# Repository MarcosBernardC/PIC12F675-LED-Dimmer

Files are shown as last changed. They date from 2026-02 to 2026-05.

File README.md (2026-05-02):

# PIC12F675 LED Dimmer





> **Nota:** Este proyecto ha sido migrado al **ARCHIVE**. Representa una base estable de control de potencia y gestión de recursos limitados en sistemas embebidos.

## 🚧 Avance Actual: Diseño de PCB y Modelado 3D
Actualmente, he finalizado el esquema lógico y la disposición de componentes principales. El siguiente paso es la integración de un módulo Buck Step-Down personalizado (LM2596) modelado en FreeCAD para mejorar la eficiencia térmica.

### Captura del Layout Preliminar
Aquí puedes ver la disposición actual de los transistores 2N2222A y los conectores JST para las 5 salidas LED.
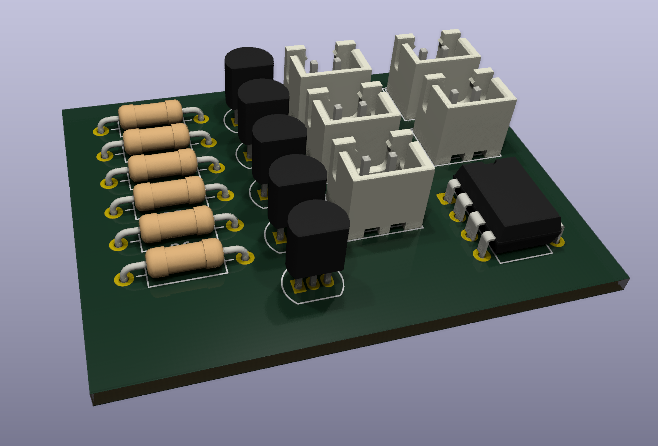
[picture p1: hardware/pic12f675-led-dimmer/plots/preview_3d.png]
Layout 3D Preliminar


---

## 📝 Descripción
Controlador de intensidad (Dimmer) de 5 canales para tiras LED de 12V, basado en el microcontrolador PIC12F675. 

* **Control:** PWM generado por software.
* **Potencia:** Transistores 2N2222A en configuración de conmutación.
* **Eficiencia:** Integración de regulador Buck LM2596 para reducir de 12V a 5V sin generar calor excesivo.

### 📂 Documentación de Hardware
Para una revisión detallada de las conexiones, consulta el <a href="https://raw.githubusercontent.com/MarcosBernardC/PIC12F675-LED-Dimmer/main/hardware/pic12f675-led-dimmer/pic12f675-led-dimmer.pdf" 
   target="_blank" 
   rel="noopener noreferrer">
   📄 <strong>Diagrama Técnico (PDF)</strong>
</a>

---

## 🧠 Firmware
El núcleo del sistema está escrito en **C** y optimizado para el PIC12F675 utilizando el compilador **XC8**.

* **Arquitectura:** Basada en interrupciones para una gestión eficiente del PWM.
* **Módulos clave:**  
    * Gestión de 5 canales de salida mediante conmutación rápida.
    * Configuración de registros internos (Oscilador, GPIO, Timers).

* **Código Fuente:** <a href="https://raw.githubusercontent.com/MarcosBernardC/PIC12F675-LED-Dimmer/main/src/main.c" target="_blank">📄 main.c (Vista Raw)</a>

---

## 🛠️ Herramientas utilizadas
* **Firmware:** C (XC8 Compiler), MPLAB X.
* **Diseño PCB:** KiCad 8.0.
* **Modelado 3D:** FreeCAD (integración paramétrica).
* **Automatización:** `Makefile` para compilación y gestión de assets.
* **Documentación:** LaTeX para el reporte de investigación.

---

## 📁 Estructura del Proyecto
* `/src`: Código fuente en C y artefactos de compilación (`.hex`).
* `/hardware`: Archivos de diseño de KiCad 8.0 y exportaciones PDF.
* `/docs`: Datasheets e investigación técnica detallada en LaTeX.
* `/simulation`: Archivos de simulación para validación lógica previa.
* `Makefile`: Automatización de la compilación del firmware.

---

## 🚀 Compilación y Uso
El proyecto utiliza un `Makefile` para automatizar las tareas:
* `make`: Compila el código fuente y genera el `.hex`.
* `make clean`: Limpia los archivos temporales de compilación.

---

## ✅ Resultados y Pruebas
El sistema ha sido validado físicamente con los siguientes resultados:
* **Estabilidad Térmica:** El regulador Buck LM2596 mantiene una temperatura operativa estable bajo carga completa (5 tiras LED).
* **Respuesta PWM:** Conmutación limpia sin parpadeo perceptible, optimizada mediante la gestión de registros del Timer0.
* **Integración Mecánica:** El modelo 3D de FreeCAD permitió un ensamble preciso dentro de la carcasa final.

## 📜 Licencia y Autoría
Este proyecto fue desarrollado íntegramente por **Marcos Bernard Calixto**.
* **Copyright:** © 2026 - No License Granted - All Rights Reserved.

---
© 2026 MB

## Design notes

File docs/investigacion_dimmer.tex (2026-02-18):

\documentclass[12pt,a4paper]{article}
\usepackage[utf8]{inputenc}
\usepackage[spanish]{babel}
\usepackage{graphicx}
\usepackage{listings} % Para mostrar tu código C elegante
\usepackage{xcolor}
\usepackage{hyperref}

\title{Implementación de Control de Potencia PWM en Microcontroladores de 8 bits}
\author{Bernard Calixto}
\date{Febrero 2026}

\begin{document}

\maketitle

\section{Introducción}
Este proyecto documenta el diseño e implementación de un dimmer para luminarias LED utilizando el microcontrolador PIC12F675. Se prioriza la optimización de recursos y el uso de herramientas Open Source en entornos Linux (Fedora).

\section{Definición del Problema}
El presente proyecto nace de la necesidad de proporcionar una iluminación dinámica y estética para un elemento ornamental sacro: una efigie de plata con arco ornamental y cintas de seda fucsia y blanca. 

El desafío técnico se divide en tres vertientes:
\begin{itemize}
    \item \textbf{Efecto Visual:} Lograr una transición de luz suave (fading) que realce el brillo del metal y la textura de la seda sin parpadeos perceptibles.
    \item \textbf{Eficiencia Lumínica:} Optimizar la posición de los emisores para evitar la pérdida de intensidad por atenuación, descartando la iluminación posterior en favor de un enfoque frontal o lateral que resalte el relieve de la plata.
    \item \textbf{Restricción de Hardware:} Implementar el control en un microcontrolador de dimensiones reducidas (PIC12F675) para que el circuito sea discreto y transportable durante las procesiones.
\end{itemize}

\section{Cronograma de Desarrollo}
\begin{itemize}
    \item \textbf{Fase 1:} Validación de hardware (Blink LED).
    \item \textbf{Fase 2:} Implementación de ADC para control analógico.
    \item \textbf{Fase 3:} Generación de señal PWM y pruebas de carga.
\end{itemize}

\end{document}

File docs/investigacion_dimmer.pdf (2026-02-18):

# Implementación de Control de Potencia PWM en Microcontroladores de 8 bits

### Bernard Calixto

### Febrero 2026

## 1. Introducción

Este proyecto documenta el diseño e implementación de un dimmer para luminarias LED utilizando el microcontrolador PIC12F675. Se prioriza la optimización de recursos y el uso de herramientas Open Source en entornos Linux (Fedora).

## 2. Definición del Problema

El presente proyecto nace de la necesidad de proporcionar una iluminación dinámica y estética para un elemento ornamental sacro: una efigie de plata con arco ornamental y cintas de seda fucsia y blanca.
El desafío técnico se divide en tres vertientes:

Efecto Visual: Lograr una transición de luz suave (fading) que realce el brillo del metal y la textura de la seda sin parpadeos perceptibles.

Eficiencia Lumínica: Optimizar la posición de los emisores para evitar la pérdida de intensidad por atenuación, descartando la iluminación posterior en favor de un enfoque frontal o lateral que resalte el relieve de la plata.

Restricción de Hardware: Implementar el control en un microcontrolador de dimensiones reducidas (PIC12F675) para que el circuito sea discreto y transportable durante las procesiones.

1

## 3. Cronograma de Desarrollo

Fase 1: Validación de hardware (Blink LED).

Fase 2: Implementación de ADC para control analógico.

Fase 3: Generación de señal PWM y pruebas de carga.

2

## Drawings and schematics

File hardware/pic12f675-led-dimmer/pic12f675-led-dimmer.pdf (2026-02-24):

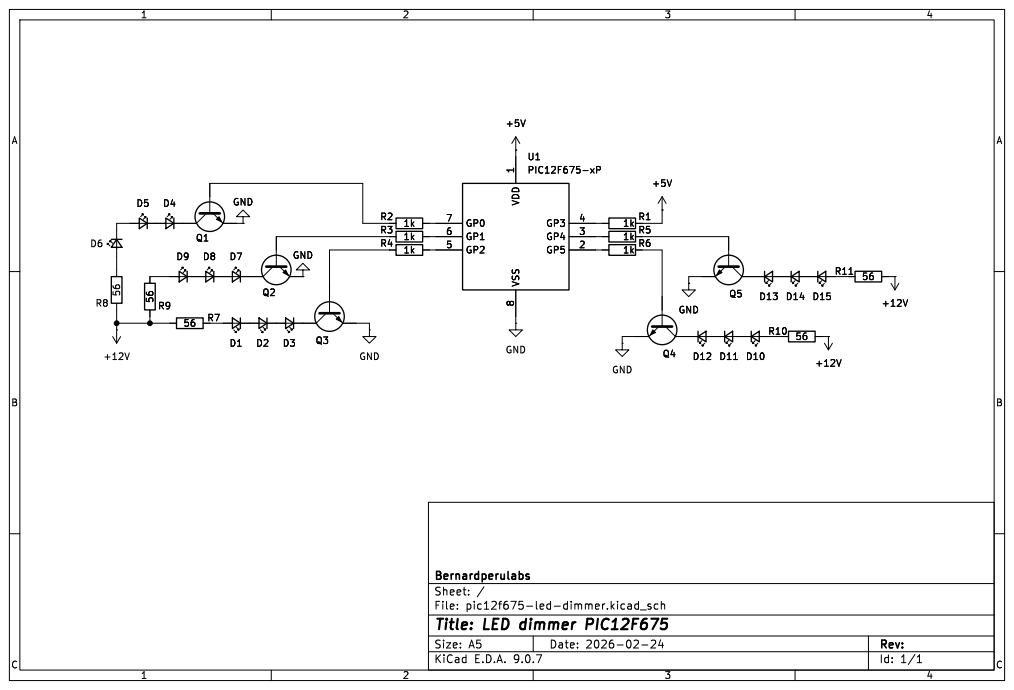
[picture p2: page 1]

Id: 1/1 Title: LED dimmer PIC12F675

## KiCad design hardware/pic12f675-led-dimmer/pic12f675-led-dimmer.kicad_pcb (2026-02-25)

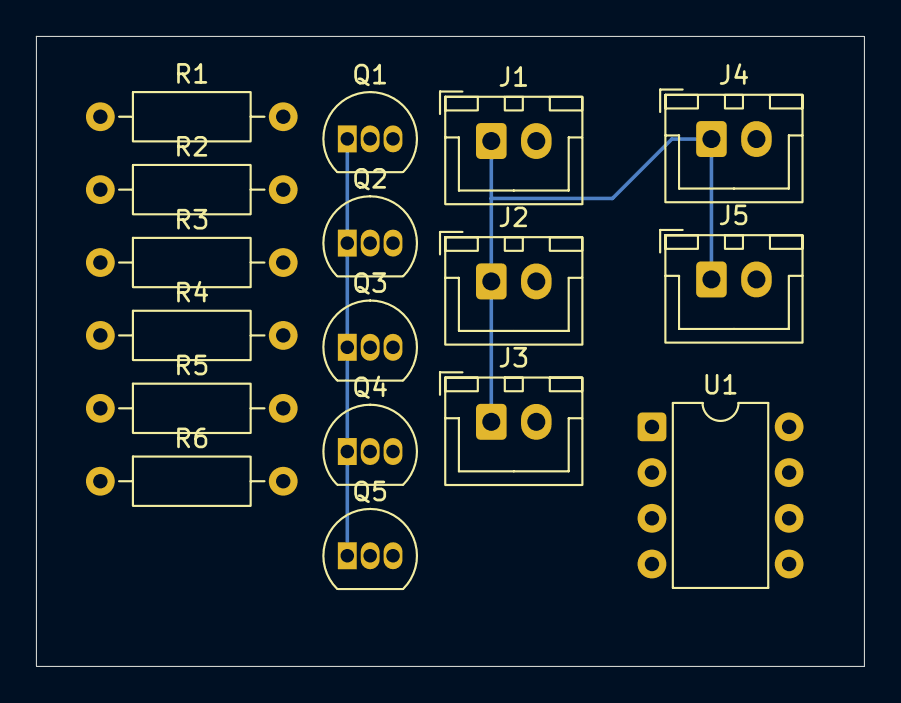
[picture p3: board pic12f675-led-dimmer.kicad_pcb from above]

Board: 2 copper layers, 46.0 x 35.0 mm, 17 parts (0 on the bottom side), 8 nets.

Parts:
J1, J2, J3, J4, J5: Conn_01x02_Pin; JST_XH_B2B-XH-A_1x02_P2.50mm_Vertical
Q1, Q2, Q3, Q4, Q5: Q_NPN; TO-92_Inline
R1, R2, R3, R4, R5, R6: 1k; R_Axial_DIN0207_L6.3mm_D2.5mm_P10.16mm_Horizontal
U1: PIC12F675-xP; DIP-8_W7.62mm

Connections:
+5V: R1.2, U1.1 (VDD)
+12V: J1.1, J2.1, J3.1, J4.1, J5.1
unnamed: R2.1, U1.7 (GP0)
unnamed: R3.1, U1.6 (GP1)
unnamed: R4.1, U1.5 (GP2)
unnamed: R1.1, U1.4 (GP3)
unnamed: R5.1, U1.3 (GP4)
unnamed: R6.1, U1.2 (GP5)

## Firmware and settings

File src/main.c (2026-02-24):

#include <xc.h>

// ---------------------------------------------------------------------------
// CONFIG — PIC12F675, fuses completos
// ---------------------------------------------------------------------------
#pragma config FOSC  = INTRCIO  // Oscilador interno, GP4/GP5 como I/O
#pragma config WDTE  = OFF      // Watchdog Timer desactivado
#pragma config PWRTE = ON       // Power-up Timer activado
#pragma config MCLRE = OFF      // GP3 como entrada digital (no reset)
#pragma config BOREN = ON       // Brown-out Reset activado
#pragma config CP    = OFF      // Sin protección de código
#pragma config CPD   = OFF      // Sin protección de datos EEPROM

#define _XTAL_FREQ 4000000UL

// ---------------------------------------------------------------------------
// Parámetros del efecto
// ---------------------------------------------------------------------------
#define PWM_STEPS   100     // Resolución PWM (0–100)
#define T0_RELOAD   156     // Timer0: tick de 200µs → PWM 50Hz @ 4MHz, prescaler 1:2
#define T1_RELOAD_H 0xF8    // Timer1: tick de 15ms @ 4MHz, prescaler 1:8
#define T1_RELOAD_L 0xED
#define ARCO_DIV    2       // Arco: 1 paso cada 2 ticks → ciclo ~6s
#define VIRGEN_DIV  4       // Virgen: 1 paso cada 4 ticks → ciclo ~12s

// ---------------------------------------------------------------------------
// Variables compartidas ISR ↔ main
// ---------------------------------------------------------------------------

// Base (GP0/GP1) — ola 3s
volatile unsigned char brillo_base   = 0;
volatile signed char   paso_base     = 1;

// Arco (GP2/GP4) — ola 6s, arranca en contrafase con base
volatile unsigned char brillo_arco   = PWM_STEPS;
volatile signed char   paso_arco     = -1;

// Virgen (GP5) — respiración lenta 12s, arranca en brillo medio
volatile unsigned char brillo_virgen = 50;
volatile signed char   paso_virgen   = 1;

// ---------------------------------------------------------------------------
// ISR
// ---------------------------------------------------------------------------
void __interrupt() isr(void) {

    // --- Timer0: PWM tick (200µs) ---
    if(INTCONbits.T0IF) {
        static unsigned char cnt = 0;

        // Base: GP0 y GP1 en contrafase
        GP0 = (cnt < brillo_base)               ? 1 : 0;
        GP1 = (cnt < (PWM_STEPS - brillo_base)) ? 1 : 0;

        // Arco: GP2 y GP4 en contrafase entre sí
        GP2 = (cnt < brillo_arco)               ? 1 : 0;
        GP4 = (cnt < (PWM_STEPS - brillo_arco)) ? 1 : 0;

        // Virgen: GP5 respiración lenta independiente
        GP5 = (cnt < brillo_virgen)             ? 1 : 0;

        if(++cnt >= PWM_STEPS) cnt = 0;

        TMR0 = T0_RELOAD;
        INTCONbits.T0IF = 0;
    }

    // --- Timer1: fade tick (15ms) ---
    if(PIR1bits.TMR1IF) {

        // -- Fade base (cada tick → ciclo ~3s) --
        if(paso_base > 0 && brillo_base >= PWM_STEPS) {
            paso_base = -1;
        } else if(paso_base < 0 && brillo_base == 0) {
            paso_base = 1;
        }
        brillo_base += paso_base;

        // -- Fade arco (cada 2 ticks → ciclo ~6s) --
        static unsigned char arco_cnt = 0;
        if(++arco_cnt >= ARCO_DIV) {
            arco_cnt = 0;
            if(paso_arco > 0 && brillo_arco >= PWM_STEPS) {
                paso_arco = -1;
            } else if(paso_arco < 0 && brillo_arco == 0) {
                paso_arco = 1;
            }
            brillo_arco += paso_arco;
        }

        // -- Fade virgen (cada 4 ticks → ciclo ~12s) --
        static unsigned char virgen_cnt = 0;
        if(++virgen_cnt >= VIRGEN_DIV) {
            virgen_cnt = 0;
            if(paso_virgen > 0 && brillo_virgen >= PWM_STEPS) {
                paso_virgen = -1;
            } else if(paso_virgen < 0 && brillo_virgen == 0) {
                paso_virgen = 1;
            }
            brillo_virgen += paso_virgen;
        }

        TMR1H = T1_RELOAD_H;
        TMR1L = T1_RELOAD_L;
        PIR1bits.TMR1IF = 0;
    }
}

// ---------------------------------------------------------------------------
// Main
// ---------------------------------------------------------------------------
void main(void) {

    ANSEL  = 0x00;
    CMCON  = 0x07;
    TRISIO = 0x00;
    GPIO   = 0x00;

    // Timer0 — preescaler 1:2, fuente interna
    OPTION_REG = 0b00000000;
    TMR0 = T0_RELOAD;
    INTCONbits.T0IE = 1;

    // Timer1 — preescaler 1:8, fuente interna
    T1CON = 0b00110001;
    TMR1H = T1_RELOAD_H;
    TMR1L = T1_RELOAD_L;
    PIE1bits.TMR1IE = 1;
    INTCONbits.PEIE = 1;

    INTCONbits.GIE  = 1;

    while(1) {
        // Base ola 3s | Arco ola 6s | Virgen respiración 12s
    }
}

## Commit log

2026-02-18 build: configurar entorno de documentacion con latexmk y estructura inicial
2026-02-18 feat: integrar simulación y estabilizar entorno de desarrollo para PIC12F675
    Este commit consolida el flujo de trabajo del proyecto:
    - Se añade el circuito de simulación profesional para SimulIDE.
    - Se integra la documentación técnica detallada en formato PDF.
    - Se estabiliza el entorno de compilación mediante el uso de XC8 v2.40 para compatibilidad nativa de arquitectura.
    - Se optimiza el archivo .gitignore para filtrar archivos temporales y de depuración de Microchip, manteniendo limpio el directorio de fuentes.
2026-02-18 build: optimizar flujo de LaTeX y limpieza de espacio de trabajo
    Se actualiza el Makefile para redirigir archivos auxiliares a docs/build y se limpia el .gitignore para mantener el directorio src libre de residuos de compilación.
2026-02-18 build: unificar flujo de trabajo y aislar directorios de construcción
    Este commit introduce mejoras significativas en la gestión del proyecto:
    - Se actualiza el Makefile para manejar de forma independiente la compilación de firmware (XC8) y documentación (LaTeX).
    - Se implementa el uso de directorios /build temporales para evitar la dispersión de archivos auxiliares en src/ y docs/.
    - Se automatiza la extracción de los binarios finales (.hex y .pdf) a sus respectivos directorios raíz.
    - Se añade la regla 'flash' para simplificar el proceso de grabación con PICkit 2.
2026-02-18 feat: ignorando directorio VideoEdit/. Firmware subido al PIC. Etapa 0 finalizada, led parpadeando con periodo de 500ms
2026-02-18 checkpoint: versión base lista para empezar con el juego de luces
2026-02-18 feat: implementar efecto ola para la base y probar en protoboard. TODO: implementar efecto para arco
2026-02-19 feat: implementar efecto ola base+arco en PIC12F675
    - Agregar fuses completos (CP=OFF, CPD=OFF, BOREN=ON) que bloqueaban el chip
    - Migrar arquitectura a timers por interrupciones (Timer0 PWM, Timer1 fade)
    - Base (GP0/GP1): contrafase suave, ciclo ~3s
    - Arco (GP2/GP4): contrafase independiente, ciclo ~6s
    - Corregir desborde unsigned en lógica de fade
    - Actualizar Makefile: quitar -V5 de pk2cmd, agregar reglas burn/erase/dump
    - TODO: implementar efecto virgen (GP5)
    [main.c]
2026-02-24 docs: integrar diseño de hardware A5 bajo la marca Bernardperulabs
    [pic12f675-led-dimmer.kicad_pcb, pic12f675-led-dimmer.kicad_sch]
2026-02-24 feat(hw): asignar huellas y definir layout preliminar de la PCB
    [pic12f675-led-dimmer.kicad_pcb, pic12f675-led-dimmer.kicad_sch]
2026-02-25 refactor(hw): preparar espacio para integración de módulo buck step-down
    [pic12f675-led-dimmer.kicad_pcb, pic12f675-led-dimmer.kicad_sch]
2026-02-25 docs: estructurar README profesional y optimizar reglas de gitignore
2026-05-02 style(docs): maquillar enlaces de documentación técnica para mejor UX
2026-05-02 docs: actualizar enlace de código fuente a vista raw con apertura en pestaña nueva
